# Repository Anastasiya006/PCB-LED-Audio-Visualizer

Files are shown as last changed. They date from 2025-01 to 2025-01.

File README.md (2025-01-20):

# PCB LED Audio Visualizer
https://github.com/user-attachments/assets/34dc9e85-68ce-4a28-94b5-732c458a7c48

## Overview
A custom audio visualizer printed circuit board (PCB), designed using KiCad and programmed with Arduino and C++, featuring interrupt-driven C++ logic to synchronize RGB LED animations with real-time audio dynamics. This design processes audio signals and displays dynamic patterns onto two 8x8 RGB LED matrices.

## Components
- **Arduino Mega 2560**: microcontroller for processing audio signals and controlling the LED matrix
- **Custom PCB**: custom-designed printed circuit board shield for Arduino
- **8x8 RGB LED Matrix**: dynamic visualization of audio signals
- **3.5mm Audio Jack**: allows for audio input from external devices

## Design
### Circuit Schematic
circuit schematic

### PCB Layout & Routing
pcb layout & routing

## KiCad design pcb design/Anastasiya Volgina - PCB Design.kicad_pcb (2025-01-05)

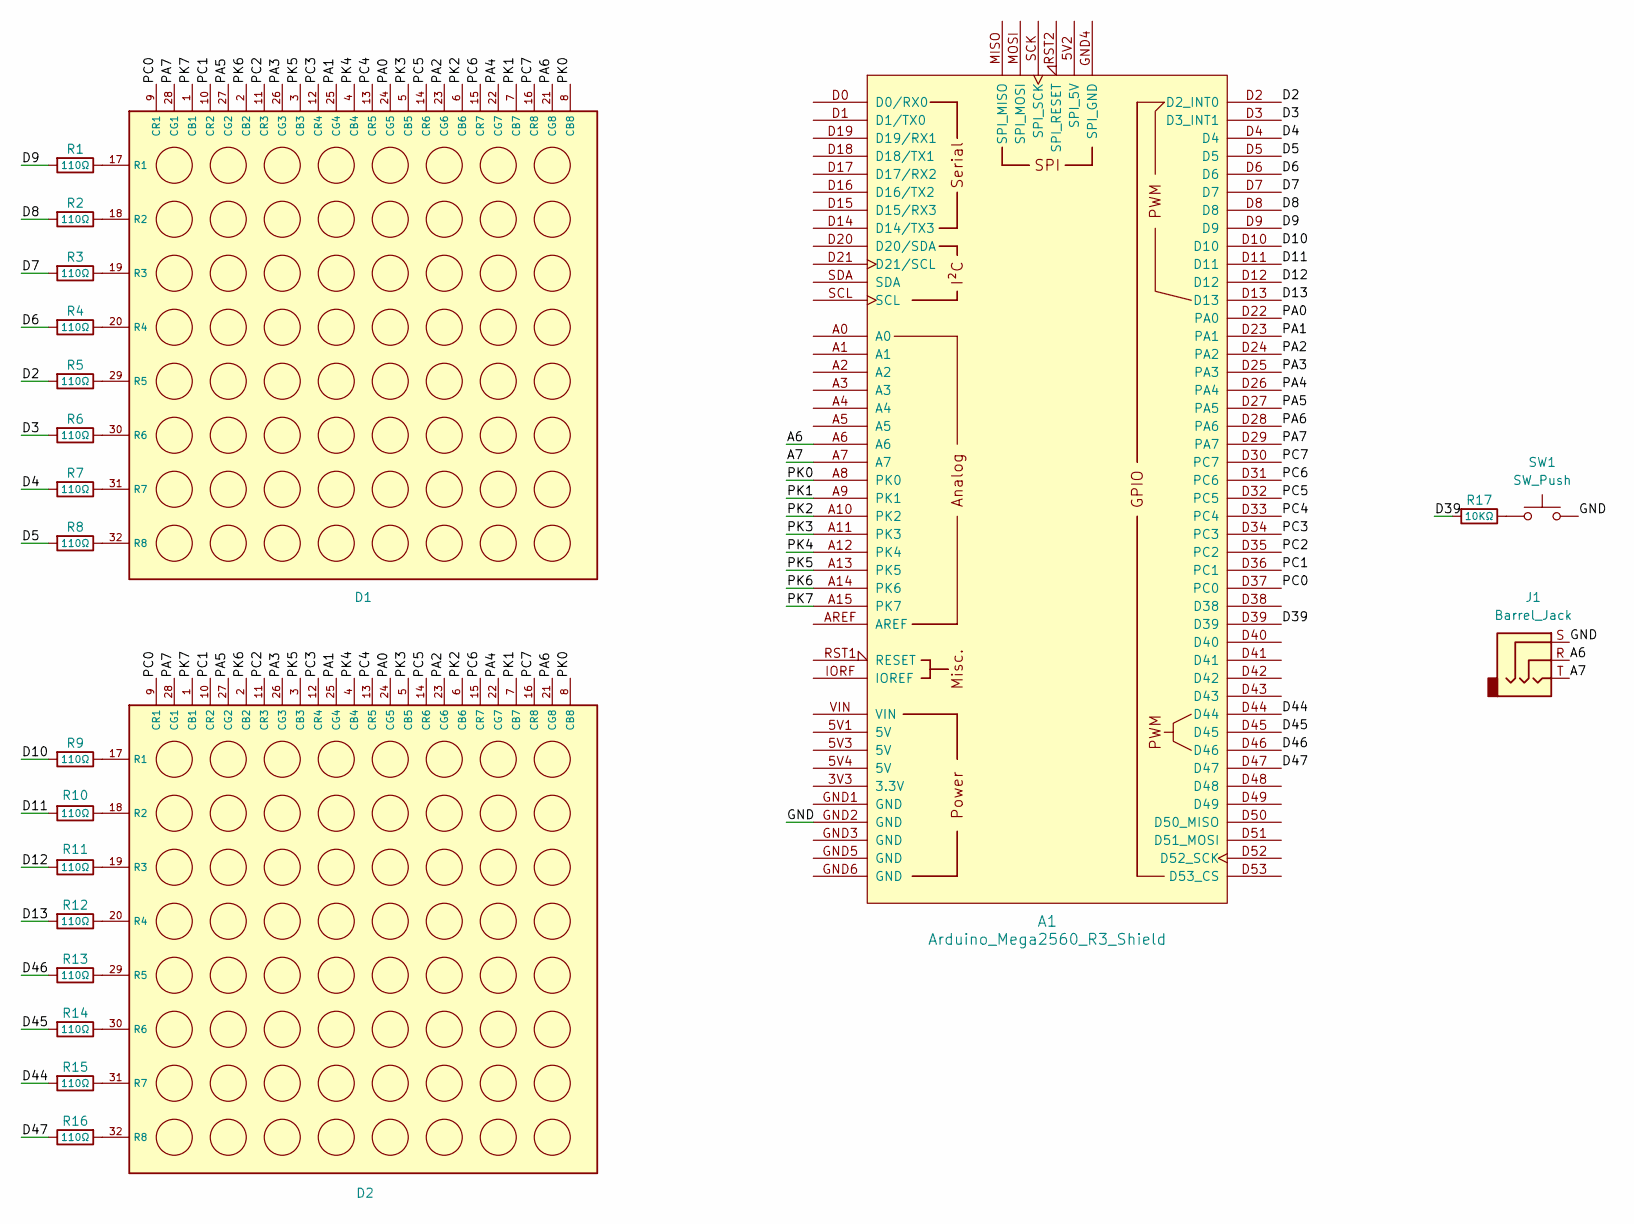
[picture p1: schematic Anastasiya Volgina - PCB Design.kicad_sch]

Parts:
A1: Arduino_Mega2560_R3_Shield
D1, D2: ORM-2388ARGB-L
J1: Barrel_Jack; Jack_3.5mm_CUI_SJ-3523-SMT_Horizontal
R1, R2, R3, R4, R5, R6, R7, R8, R9, R10, R11, R12, R13, R14, R15, R16: 110Ω; R_Axial_DIN0204_L3.6mm_D1.6mm_P5.08mm_Horizontal
R17: 10KΩ; R_Axial_DIN0204_L3.6mm_D1.6mm_P5.08mm_Horizontal
SW1: SW_Push; SW_1825910-6-4

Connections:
/A6: A1.A6, J1.R
/A7: A1.A7, J1.T
/A8: A1.A8 (PK0), D1.8 (CB8), D2.8 (CB8)
/A9: A1.A9 (PK1), D1.7 (CB7), D2.7 (CB7)
/A10: A1.A10 (PK2), D1.6 (CB6), D2.6 (CB6)
/A11: A1.A11 (PK3), D1.5 (CB5), D2.5 (CB5)
/A12: A1.A12 (PK4), D1.4 (CB4), D2.4 (CB4)
/A13: A1.A13 (PK5), D1.3 (CB3), D2.3 (CB3)
/A14: A1.A14 (PK6), D1.2 (CB2), D2.2 (CB2)
/A15: A1.A15 (PK7), D1.1 (CB1), D2.1 (CB1)
/D2: A1.D2 (D2_INT0), R5.2
/D3: A1.D3 (D3_INT1), R6.2
/D4: A1.D4, R7.2
/D5: A1.D5, R8.2
/D6: A1.D6, R4.2
/D7: A1.D7, R3.2
/D8: A1.D8, R2.2
/D9: A1.D9, R1.2
/D10: A1.D10, R9.2
/D11: A1.D11, R10.2
/D12: A1.D12, R11.2
/D13: A1.D13, R12.2
/D22: A1.D22 (PA0), D1.24 (CG5), D2.24 (CG5)
/D23: A1.D23 (PA1), D1.25 (CG4), D2.25 (CG4)
/D24: A1.D24 (PA2), D1.23 (CG6), D2.23 (CG6)
/D25: A1.D25 (PA3), D1.26 (CG3), D2.26 (CG3)
/D26: A1.D26 (PA4), D1.22 (CG7), D2.22 (CG7)
/D27: A1.D27 (PA5), D1.27 (CG2), D2.27 (CG2)
/D28: A1.D28 (PA6), D1.21 (CG8), D2.21 (CG8)
/D29: A1.D29 (PA7), D1.28 (CG1), D2.28 (CG1)
/D30: A1.D30 (PC7), D1.16 (CR8), D2.16 (CR8)
/D31: A1.D31 (PC6), D1.15 (CR7), D2.15 (CR7)
/D32: A1.D32 (PC5), D1.14 (CR6), D2.14 (CR6)
/D33: A1.D33 (PC4), D1.13 (CR5), D2.13 (CR5)
/D34: A1.D34 (PC3), D1.12 (CR4), D2.12 (CR4)
/D35: A1.D35 (PC2), D1.11 (CR3), D2.11 (CR3)
/D36: A1.D36 (PC1), D1.10 (CR2), D2.10 (CR2)
/D37: A1.D37 (PC0), D1.9 (CR1), D2.9 (CR1)
/D39: A1.D39, R17.2
/D44: A1.D44, R15.2
/D45: A1.D45, R14.2
/D46: A1.D46, R13.2
/D47: A1.D47, R16.2
/GND: A1.GND2 (GND), J1.S, SW1.2
unnamed: D1.17 (R1), R1.1
unnamed: D1.18 (R2), R2.1
unnamed: D1.19 (R3), R3.1
unnamed: D1.20 (R4), R4.1
unnamed: D1.29 (R5), R5.1
unnamed: D1.30 (R6), R6.1
unnamed: D1.31 (R7), R7.1
unnamed: D1.32 (R8), R8.1
unnamed: D2.17 (R1), R9.1
unnamed: D2.18 (R2), R10.1
unnamed: D2.19 (R3), R11.1
unnamed: D2.20 (R4), R12.1
unnamed: D2.29 (R5), R13.1
unnamed: D2.30 (R6), R14.1
unnamed: D2.31 (R7), R15.1
unnamed: D2.32 (R8), R16.1
unnamed: R17.1, SW1.1

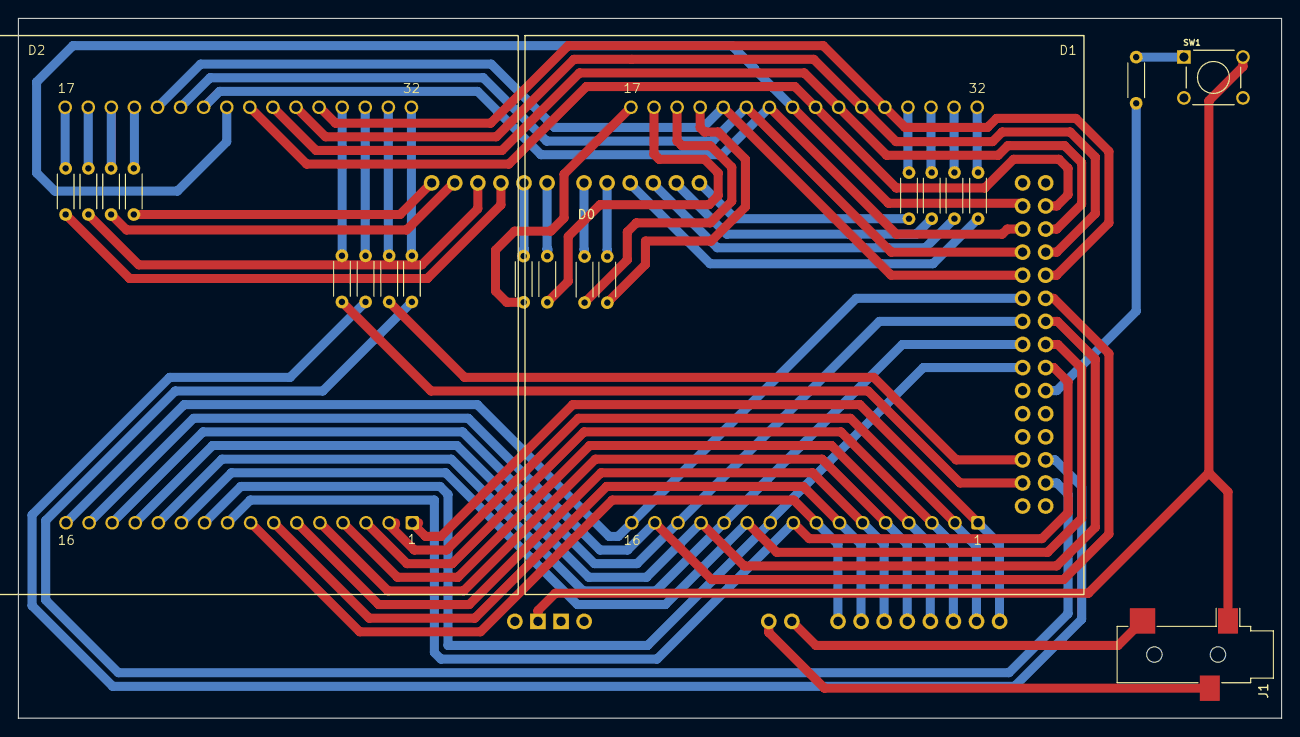
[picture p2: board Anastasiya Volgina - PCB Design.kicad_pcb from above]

Board: 2 copper layers, 139.0 x 77.0 mm, 22 parts (0 on the bottom side), 61 nets.

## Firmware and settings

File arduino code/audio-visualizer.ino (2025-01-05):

#define BUTTON 39   // button pin
#define AUDIO_R A6  // right audio channel input
#define AUDIO_T A7  // left audio channel input

// colours for matrices
const int RED = 0;      
const int GREEN = 1;   
const int BLUE = 2;

// current colour for matrices
int curr_colour = RED;

// matrix M1
const byte leftRows[8] = { 9, 8, 7, 6, 13, 12, 11, 10 };  // row pins

// matrix M2 (closer to the connector)
const byte rightRows[8] = { 47, 44, 45, 46, 2, 3, 4, 5 };  // row pins

// temporary holders for PORTS
int red = 255;
int green = 255;
int blue = 255;

const int VOL_RANGE = 128;
int volumes[16] = { 0, 0, 0, 0, 0, 0, 0, 0, 0, 0, 0, 0, 0, 0, 0, 0 }; // volume to be displayed for each column

int counter = 0;

void setup() {
  cli();  // disable all interrupts

  TCCR1A = 0;                           // clear the two Timer/Counter Control Registers (TCR) for Timer1
  TCCR1B = 0;                           //
  TCCR1B |= (1 << WGM12);               // turn on Clear Timer on Compare (CTC) mode
  TCCR1B |= (1 << CS12) | (1 << CS10);  // set CS12 and CS10 bits for prescaler_value = 1024

  TCNT1 = 0;    // initialize the Timer/Counter value to 0
  OCR1A = 312;  // set OCR = [ 16,000,000/1024 * 1 ] - 1
                // thus, the interrupt will occur every 1 second

  TIMSK1 |= (1 << OCIE1A);  // enable interrupts from Timer1 when TCNT1 reaches OCR1A value
  sei();                    // enable interrupts

  // set up ports for red, green, blue - outputs
  DDRK = B11111111;  // doesn't need to be reversed (red)
  DDRA = B11111111;  // needs to be reversed (green)
  DDRC = B11111111;  // needs to be reversed (blue)
  PORTK = 255;
  PORTA = 255;
  PORTC = 255;

  // setup both matrix rows as outputs
  for (byte i = 0; i < 8; i++) {
    pinMode(rightRows[i], OUTPUT);
    pinMode(leftRows[i], OUTPUT);
  }

  analogReference(INTERNAL1V1);

  // setup audio inputs
  pinMode(AUDIO_R, INPUT);
  pinMode(AUDIO_T, INPUT);

  // setup button
  pinMode(BUTTON, INPUT_PULLUP);

  Serial.begin(9600);
}

// calculates the power of a base to the indicated exponent
int power(int b, int exp) {
  int r = 1;

  for (int i = 0; i < exp; i++) {
    r = r * b;
  }

  return r;
}

// shifts an array of any size one position to the right
void shiftArr(int arr[], int size) {
  for (int i = size - 1; i > 0; i--) {
    arr[i] = arr[i - 1];
  }
}

ISR(TIMER1_COMPA_vect) {
  if (counter == 100) {
    curr_colour = (curr_colour + 1) % 3; // change the colour of the matrices
    counter = 0;
  }

  switch (curr_colour) {
    case RED:
      // M2
      for (int i = 0; i < 8; i++) {
        red = 0;
        for (int j = 0; j < 8; j++) {
          if (i >= volumes[j]) {
            red += power(2, j);
          }
        }
        PORTK = red;

        digitalWrite(rightRows[i], HIGH);
        delay(1);
        digitalWrite(rightRows[i], LOW);
      }

      // M1
      for (int i = 0; i < 8; i++) {
        red = 0;

        for (int j = 8; j < 16; j++) {
          if (i >= volumes[j]) {
            red += power(2, j % 8);
          }
        }
        PORTK = red;

        digitalWrite(leftRows[i], HIGH);
        delay(1);
        digitalWrite(leftRows[i], LOW);
      }
      break;
    case GREEN:
      // M2
      for (int i = 0; i < 8; i++) {
        green = 0;
        for (int j = 0; j < 8; j++) {
          if (i >= volumes[j]) {
            green += power(2, 7-j);
          }
        }
        PORTA = green;

        digitalWrite(rightRows[i], HIGH);
        delay(1);
        digitalWrite(rightRows[i], LOW);
      }

      // M1
      for (int i = 0; i < 8; i++) {
        green = 0;

        for (int j = 8; j < 16; j++) {
          if (i >= volumes[j]) {
            green += power(2, 7-j % 8);
          }
        }
        PORTA = green;

        digitalWrite(leftRows[i], HIGH);
        delay(1);
        digitalWrite(leftRows[i], LOW);
      }
      break;
    case BLUE:
      // M2
      for (int i = 0; i < 8; i++) {
        blue = 0;
        for (int j = 0; j < 8; j++) {
          if (i >= volumes[j]) {
            blue += power(2, 7-j);
          }
        }
        PORTC = blue;

        digitalWrite(rightRows[i], HIGH);
        delay(1);
        digitalWrite(rightRows[i], LOW);
      }

      // M1
      for (int i = 0; i < 8; i++) {
        blue = 0;

        for (int j = 8; j < 16; j++) {
          if (i >= volumes[j]) {
            blue += power(2, 7-j % 8);
          }
        }
        PORTC = blue;

        digitalWrite(leftRows[i], HIGH);
        delay(1);
        digitalWrite(leftRows[i], LOW);
      }
      break;
  }

  counter++;
}

void loop() {
  volumes[0] = analogRead(AUDIO_R) / VOL_RANGE; // get the audio's current volume

  shiftArr(volumes, 16);
}

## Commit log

2025-01-05 Arduino Code
2025-01-05 PCB Design
    [Anastasiya Volgina - PCB Design-B_Cu.gbr, Anastasiya Volgina - PCB Design-B_Mask.gbr, Anastasiya Volgina - PCB Design-B_Paste.gbr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]
